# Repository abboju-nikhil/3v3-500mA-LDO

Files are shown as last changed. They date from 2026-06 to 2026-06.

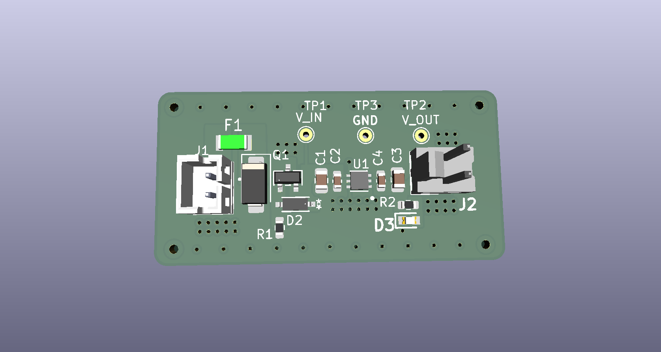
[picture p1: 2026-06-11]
Layout/3D_Image.png

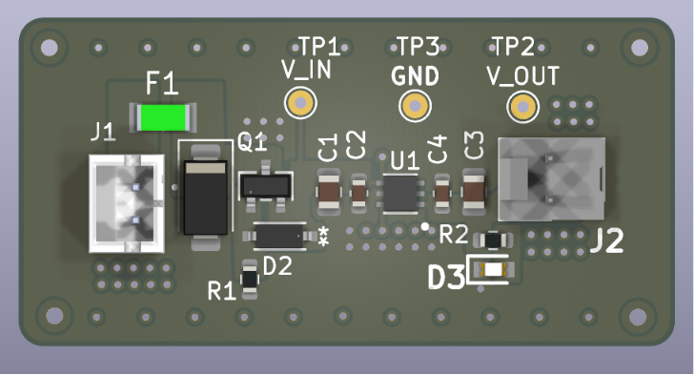
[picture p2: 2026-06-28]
Layout/3D image front.png

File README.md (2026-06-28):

# Single-Cell Li-Ion 3.3V / 500mA Low-Noise Power Supply

> A compact, robust, low-noise **3.3V linear regulator PCB** designed for **single-cell Li-ion batteries**, featuring comprehensive input protection, thermal optimization, and debugging support. Ideal for embedded systems, RF modules, sensors, and precision analog applications. 

---

## 📌 Overview

This project implements a **2-layer PCB** that converts the output of a **single-cell Li-ion battery (3.8V–4.2V)** into a clean, regulated **3.3V** supply capable of delivering up to **500mA** continuous current.

The design emphasizes:

* Low output noise
* High reliability
* Battery efficiency
* Robust input protection
* Thermal performance
* Easy testing and debugging

---

## ✨ Features

* 🔋 Single-cell Li-ion input (3.8V–4.2V)
* ⚡ Fixed 3.3V regulated output
* 🔌 500mA continuous output current
* 🛡 Reverse polarity protection
* ⚠ Resettable overcurrent protection (PTC Fuse)
* ⚡ TVS surge & ESD protection
* 🔥 Thermal pad with via array
* 💡 Power indication LED
* 📈 Dedicated test points
* 🧩 2-layer PCB with optimized power routing

---

## 📊 Specifications

| Parameter | Value |
| --- | --- |
| Input Voltage | 3.8V–4.2V DC |
| Output Voltage | 3.3V DC |
| Output Current | 500mA Max |
| Typical Load | 450mA |
| Operating Temperature | 0°C–70°C |
| PCB Layers | 2 |
| Board Size | <40mm × 20mm |

---

# Architecture

```text
Li-Ion Battery
      │
      ▼
Resettable PTC Fuse
      │
      ▼
TVS Diode Protection
      │
      ▼
P-Channel MOSFET
(Reverse Polarity Protection)
      │
      ▼
LP5912-3.3 LDO
      │
      ▼
Output Capacitors
      │
      ▼
3.3V Output Connector
```

---

# Main Components

| Reference | Part | Purpose |
| --- | --- | --- |
| U1 | LP5912-3.3DRVR | 500mA Low-Noise LDO |
| Q1 | DMP2035U-7 | Reverse Polarity Protection |
| F1 | MF-NSMF110-2 | Resettable PTC Fuse |
| D1 | SMAJ5.0CA | TVS Surge Protection |
| D2 | BZT52C6V8 | MOSFET Gate Protection |
| D3 | Green LED | Power Indicator |
| C1 | 22µF | Input Bulk Capacitor |
| C2 | 100nF | Input Decoupling |
| C3 | 10µF | Output Stability |
| C4 | 100nF | High-Frequency Filtering |

---

# Protection Features

## Reverse Polarity Protection

A **DMP2035U-7 P-Channel MOSFET** replaces the traditional Schottky diode, providing:

* Lower voltage drop
* Higher efficiency
* Better battery utilization
* Automatic reverse battery protection

---

## Overcurrent Protection

The **MF-NSMF110-2 resettable PTC fuse** protects against:

* Output short circuits
* Component failures
* Excessive current draw

The fuse automatically resets once the fault is removed.

---

## Surge & ESD Protection

A **SMAJ5.0CA TVS diode** protects the input from:

* ESD events
* Hot-plug transients
* Voltage spikes
* Input surges

---

## MOSFET Gate Protection

A **6.8V Zener diode (BZT52C6V8)** limits the gate-to-source voltage to protect the MOSFET during transient events.

---

# Capacitor Configuration

## Input Side

| Component | Function |
| --- | --- |
| 22µF | Bulk energy storage |
| 100nF | High-frequency noise filtering |

Placed close to the regulator input to minimize parasitic inductance.

---

## Output Side

| Component | Function |
| --- | --- |
| 10µF | Stability & transient response |
| 100nF | High-frequency filtering |

Located directly beside the regulator output pin.

---

# Test Points

For simplified debugging and validation:

| Test Point | Signal |
| --- | --- |
| TP1 | VIN |
| TP2 | VOUT |
| TP3 | GND |

Compatible with multimeters and oscilloscopes.

---

# Thermal Design

Worst-case power dissipation:

```text
P = (VIN − VOUT) × IOUT

= (4.2 − 3.3) × 0.5

≈ 0.45 W
```

Thermal improvements include:

* Exposed thermal pad
* Thermal via array
* Continuous ground plane
* Ground stitching vias

These features improve heat dissipation and ensure reliable operation within the specified temperature range.

---

# PCB Layout Highlights

* 2-layer PCB
* Continuous bottom ground plane
* Wide VIN/VOUT copper pours
* Short power paths
* Thermal vias beneath LDO
* Ground stitching
* 45° trace routing
* Clearly labeled silkscreen
* Dedicated debugging test points

---

# Applications

This board is suitable for:

* 🤖 Embedded Systems
* 📡 RF Modules
* 📟 IoT Devices
* 🌡 Sensor Nodes
* 🎧 Low-Noise Analog Circuits
* 🔬 Laboratory Prototypes
* 📷 Portable Electronics

---

# Repository Structure

```text
├── Hardware/
│   ├── Schematic/
│   ├── PCB/
│   ├── Gerbers/
│   └── BOM/
│
├── Images/
│   ├── PCB_3D.png
│   ├── Top_View.png
│   └── Bottom_View.png
│
├── Datasheets/
│
├── Docs/
│   └── Design_Notes.pdf
│
└── README.md
```

---

# Future Improvements

* Buck-Boost version for full battery discharge operation
* Battery charging circuit integration
* Fuel gauge implementation
* USB Type-C power input
* Power-path management
* Load switch enable/disable control

---

# License

This project is released under the **MIT License**.

---

## 👨‍💻 Author

**Nikhil Abboju**
Power Electronics Engineer | PCB Design | Embedded Hardware | KiCad

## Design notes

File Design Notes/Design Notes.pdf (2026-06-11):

## Design Notes – Single-Cell Li-Ion 3.3V / 500mA Regulator Board

### 1 Design Overview

This design implements a compact battery-powered 3.3V regulated power supply intended for embedded, RF, sensor, and low-noise analog applications. The board converts the output of a single-cell Li-ion battery (3.8V–4.2V nominal operating range) into a regulated 3.3V supply capable of delivering up to 500mA continuous output current.
The design incorporates reverse-polarity protection, transient suppression, overcurrent protection, power indication, thermal management, and dedicated test points for validation and debugging.

### 1.1 Key Specifications

Parameter | Value
Input Voltage | 3.8V – 4.2V DC (Single-Cell Li-Ion)
Output Voltage | 3.3V DC
Maximum Output Current 500mA
Typical Application Load | 450mA
Operating Temperature | 0°C to 70°C
PCB Layers | 2
Form Factor | < 40mm × 20mm

### 2 IC Selection

### 2.1 LP5912-3.3DRVR (U1)

The LP5912-3.3DRVR low-noise LDO regulator from Texas Instruments was selected as the primary voltage regulation device.
Key advantages include:
- Fixed 3.3V output
- 500mA output current capability
- Very low dropout voltage
- Low output noise performance
- High power-supply rejection ratio (PSRR)
- Integrated thermal shutdown and current limiting
- Compact WSON package with exposed thermal pad
The LP5912 is particularly well suited for battery-powered applications where low noise and low dropout voltage are critical requirements.

### 3 Protection Circuitry

### 3.1 Reverse Polarity Protection (Q1)

Q1 (DMP2035U-7 P-Channel MOSFET) provides reverse-polarity protection at the battery input. Compared to a conventional Schottky diode solution, the MOSFET introduces significantly lower voltage drop, preserving valuable headroom for the LDO regulator and maximizing battery utilization.
Benefits:
- Low forward voltage loss
- High efficiency
- No significant impact on dropout margin
- Automatic protection against reverse battery insertion

### 3.2 Overcurrent Protection (F1)

F1 (MF-NSMF110-2 Resettable PTC Fuse) provides input overcurrent protection.
The device protects the battery and PCB from excessive current during fault conditions such as:
- Output short circuits
- Component failures
- Input protection failures
The resettable nature of the fuse allows normal operation to resume automatically after fault removal.

### 3.3 Input Transient Protection (D1)

D1 (SMAJ5.0CA) is a bidirectional transient voltage suppressor (TVS) diode connected across the battery input.
Functions:
- ESD protection
- Hot-plug transient suppression
- Input surge suppression
- Protection against positive and negative voltage spikes
The device is located adjacent to the input connector to minimize transient propagation into the remainder of the circuit.

### 3.4 MOSFET Gate Protection (D2)

D2 (BZT52C6V8) is a 6.8V zener diode connected between the MOSFET gate and source. Functions:
- Limits gate-to-source voltage
- Protects the MOSFET from gate overstress
- Improves robustness during transient events

### 4 Input and Output Capacitors

### 4.1 Input Capacitors (C1, C2)

### C1 – 22µF Bulk Capacitor

Provides:
- Input energy storage

- Load transient support
- Battery impedance reduction

### C2 – 100nF Ceramic Capacitor

Provides:
- High-frequency decoupling
- Noise suppression
- Improved regulator stability
Both capacitors are placed close to the LP5912 input pin to minimize parasitic inductance.

### 4.2 Output Capacitors (C3, C4)

### C3 – 10µF Ceramic Capacitor

Primary output capacitor used for:
- Regulator stability
- Load transient response
- Output ripple reduction

### C4 – 100nF Ceramic Capacitor

Provides:
- High-frequency output filtering
- Improved dynamic response
The capacitors are positioned directly adjacent to the regulator output and output connector.

### 5 Power Indicator

### 5.1 LED Indicator (D3)

A green LED is connected to the regulated 3.3V output rail through resistor R2. Functions:
- Visual confirmation of regulator operation
- Output power status indication
The LED illuminates whenever the 3.3V rail is present.

### 6 Test Points

Dedicated test points are provided for validation and troubleshooting.

### Test Point Signal

TP1 | VIN
TP2 | VOUT
TP3 | GND

These test points allow direct probing using multimeters and oscilloscopes without disturbing the circuit.

### 7 Thermal Design

The worst-case regulator dissipation occurs at maximum battery voltage and maximum load current.
Approximate worst-case dissipation:

P ≈ (4.2V − 3.3V) × 0.5A ≈ 0.45W

The LP5912 exposed thermal pad is connected directly to the ground plane through a thermal-via array beneath the package.
Thermal management features include:
- Exposed-pad grounding
- Thermal vias beneath U1
- Additional surrounding ground vias
- Continuous bottom-layer ground plane
These measures improve heat transfer into the PCB and maintain safe operating temperatures across the specified ambient temperature range.

### 8 PCB Layout Decisions

The PCB follows a left-to-right power flow architecture:

Battery Input
↓
PTC Fuse
↓
TVS Protection
↓
P-MOS Reverse Protection
↓
LP5912 LDO
↓
Output Capacitors
↓
Output Connector

This arrangement minimizes power-path length and reduces voltage drop.

### 8.1 Layout Features

- 2-layer PCB construction
- Continuous ground plane on bottom layer
- Ground stitching vias around board perimeter
- Short power paths
- Wide copper regions for VIN and VOUT
- Thermal-via array beneath regulator
- Dedicated test points
- 45° routing practices
- Silkscreen labels for connectors and test points
The layout was optimized for manufacturability, thermal performance, and electrical robustness while remaining within the required board size constraints.

### 9 Conclusion

The completed design provides a compact and robust 3.3V power supply solution for single-cell Li-ion battery applications. The design integrates voltage regulation, reverse-polarity protection, transient suppression, overcurrent protection, thermal management, power indication, and debugging access while maintaining compatibility with standard low-cost 2-layer PCB fabrication processes. The design comfortably supports the specified 500mA output requirement and is suitable for powering embedded systems, RF modules, sensors, and low-noise analog circuitry.

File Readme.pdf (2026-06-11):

Single-Cell Li-Ion 3.3V / 500mA Low- Noise Power Supply

Professional GitHub README Documentation

Project Overview

A compact, low-noise, and highly protected 3.3V power supply designed for battery- powered embedded applications. The design converts a single-cell Li-Ion battery output into a regulated 3.3V rail capable of supplying up to 500mA continuous current. Key Specifications
Input Voltage: 3.8V–4.2V DC
Output Voltage: 3.3V DC
Maximum Output Current: 500mA
Typical Load Current: 450mA PCB Layers: 2
Operating Temperature: 0°C–70°C
Board Size: < 40mm × 20mm

Applications

Embedded Systems, IoT Devices, Wireless Sensor Nodes, RF Modules, Portable Electronics, Low-Noise Analog Circuits, Battery-Powered Development Platforms. Hardware Architecture Battery Input → PTC Fuse → TVS Protection → Reverse Polarity MOSFET → LP5912 LDO Regulator → Output Filtering → 3.3V Output

Major Components

LP5912-3.3DRVR Low-Noise LDO Regulator, DMP2035U-7 P-Channel MOSFET, MF- NSMF110-2 Resettable Fuse, SMAJ5.0CA TVS Diode, BZT52C6V8 Zener Diode. Protection Features
Reverse polarity protection, overcurrent protection, surge suppression, ESD protection, and MOSFET gate protection.

Filtering and Stability

22µF and 100nF input capacitors provide bulk storage and decoupling. 10µF and 100nF output capacitors ensure stability and transient performance. Thermal Design
Worst-case regulator dissipation is approximately 0.45W. Thermal management is achieved using an exposed pad, thermal vias, ground stitching vias, and a continuous ground plane. Test Points TP1: VIN, TP2: VOUT, TP3: GND. PCB Layout Features
2-layer PCB, continuous ground plane, thermal via array, wide power traces, short current paths, 45-degree routing, and clear silkscreen labeling. Project Status
Schematic Complete, PCB Layout Complete, ERC Passed, DRC Passed, Manufacturing Files Generated, Ready for Fabrication. Repository Contents
schematic/, Layout/, Gerber files/, Drill files/, BOM/, Datasheets/, Design Notes/, 3D_Models/, symbols/, footprints/, README.md

Tools Used

KiCad 10, Manufacturer Datasheets, Standard 2-Layer PCB Design Practices. Author
Abboju Nikhil – Power Electronics Engineer | PCB Design Engineer

License

Provided for educational, portfolio, and learning purposes.

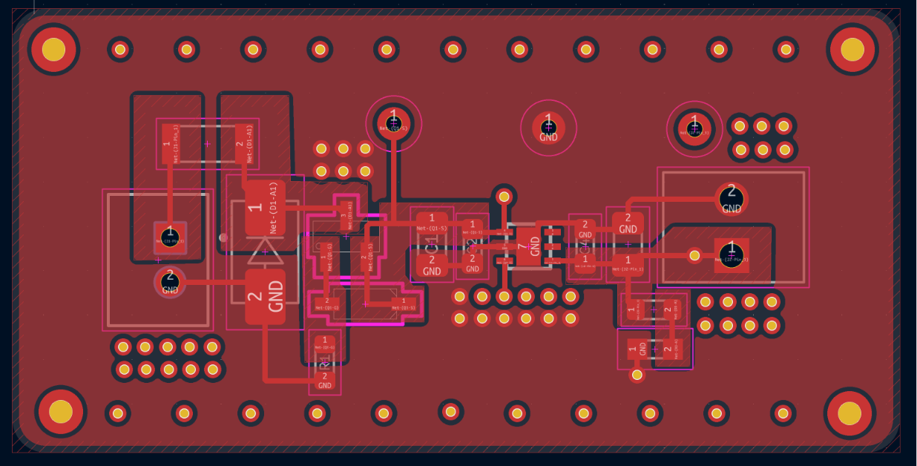
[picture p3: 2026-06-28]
Layout/Fcu.png

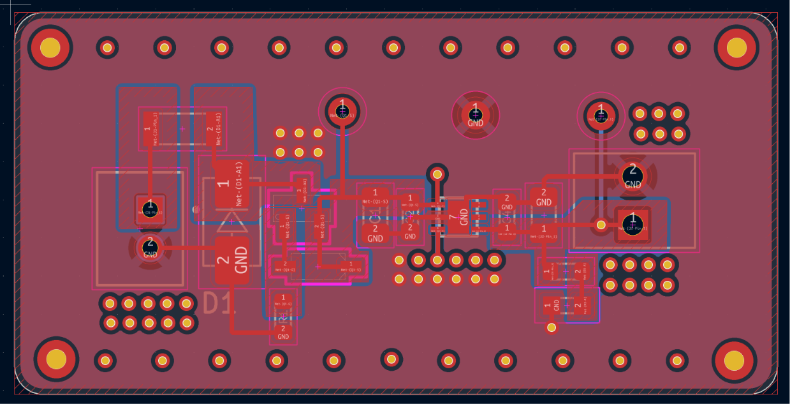
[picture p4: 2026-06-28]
Layout/All Layers .png

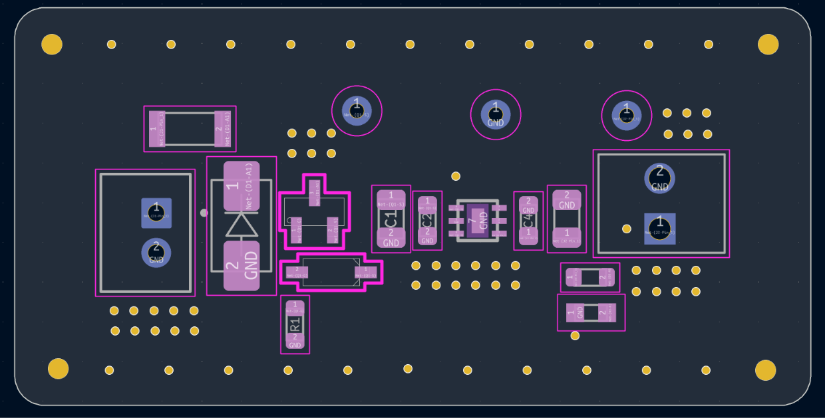
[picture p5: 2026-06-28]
Layout/Edgecuts.png

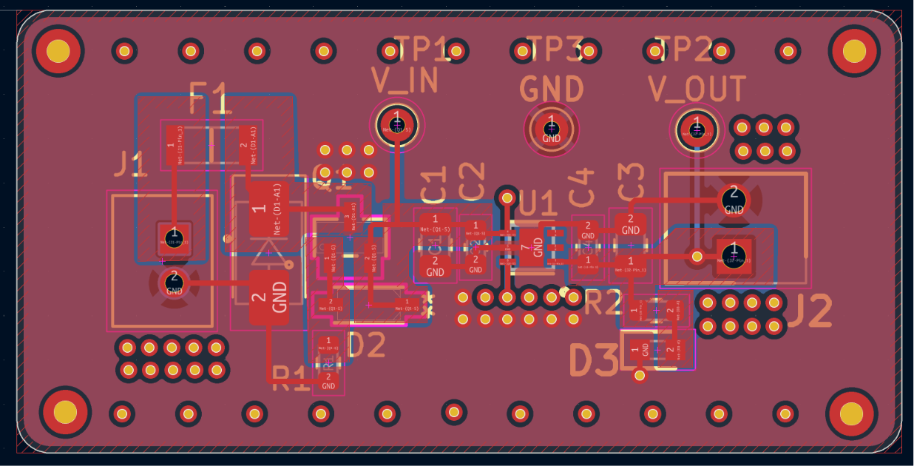
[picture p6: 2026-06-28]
Layout/ALL LAYERS 2.png

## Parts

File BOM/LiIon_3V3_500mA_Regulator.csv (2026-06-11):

Reference | Value | Description | Manufacturer | MPN
C1 | 22uF/16V | 22 uF +/-20% 16V Ceramic Capacitor X5R 0805 (2012 Metric) | Samsung Electro-Mechanics | CL21A226MOQNNNE
C2,C4 | 100nF/16V | CAP CER 0.1UF 16V X7R 0603 | Murata Electronics | GCM188R71C104KA37J
C3 | 10uF/16V | CAP CER 10UF 16V X7R 0805 | Murata Electronics | GRM21BZ71C106KE15L
D1 | SMAJ5.0CA | 400W bidirectional Transient Voltage Suppressor, 5.0Vr, SMA(DO-214AC) | LITTELFUSE | SMAJ5.0CA
D2 | 6.8V | Zener Diode 6.8V, 500mW, SOD-123 | Diodes Incorporated | BZT52C6V8-7-F
D3 | LTST-C190KGKT | Green Indicator LED, 0603 | Lite-On | LTST-C190KGKT
F1 | MF-NSMF110-2 | Fuse, PTC, Resettable, SMD, 1206, 1.1A Bourns 1.1A Surface Mount Resettable Fuse, 6 V | Bourns | MF-NSMF110-2
J1 | JST-PH 2PIN | 2-Pin PH Connector Header, 2.0mm Pitch | JST Sales America Inc. | B2B-PH-K-S
J2 | 2 PIN HEADER | 2-Pin Header, 2.54mm Pitch, THT | Molex | 22-23-2021
Q1 | DMP2035U-7 | P-CH MOSFET, -20V, -3.6A, SOT-23 | Diodes Incorporated | DMP2035U-7
R1 | 100K | RES 100K OHM 1% 1/10W 0603 | YAGEO | RC0603FR-07100KL
R2 | 10K | RES 10K OHM 1% 1/10W 0603 | YAGEO | RC0603FR-0710KL
TP1,TP2,TP3 | GND,V_IN,V_OUT | test point
U1 | LP5912-3.3DRVR | Low-Noise 3.3V LDO, 500mA, WSON-6 | Texas Instruments | LP5912-3.3DRVR

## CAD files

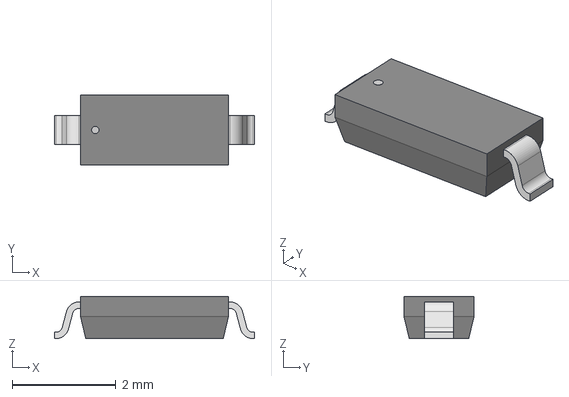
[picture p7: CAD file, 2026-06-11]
3D_Models/SOD123_DIO.step
3.85 x 1.35 x 0.815 mm

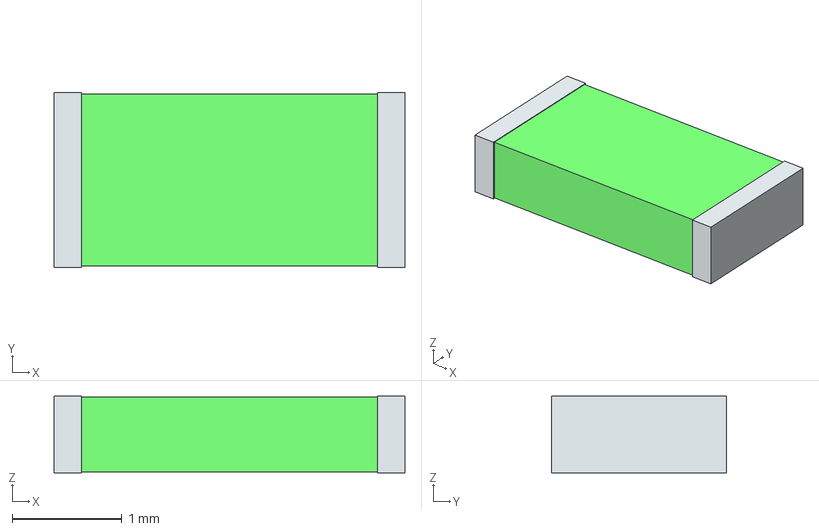
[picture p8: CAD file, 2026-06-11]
3D_Models/MF-NSMF110-2.stp
3.20 x 1.60 x 0.7 mm
term1
term2

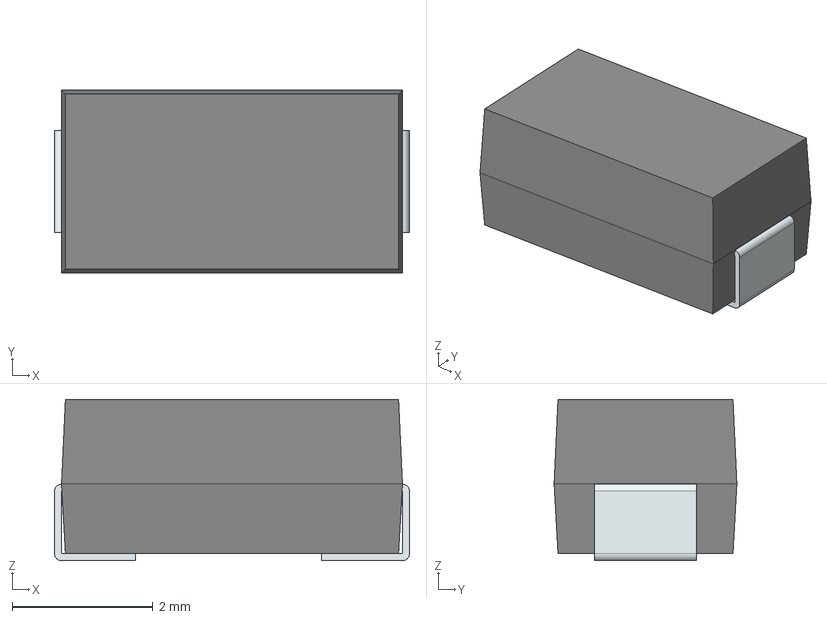
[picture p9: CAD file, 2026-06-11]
3D_Models/SMAJ5.0CA.stp
5.04 x 2.60 x 2.29 mm
FilletPin1
FilletPin2

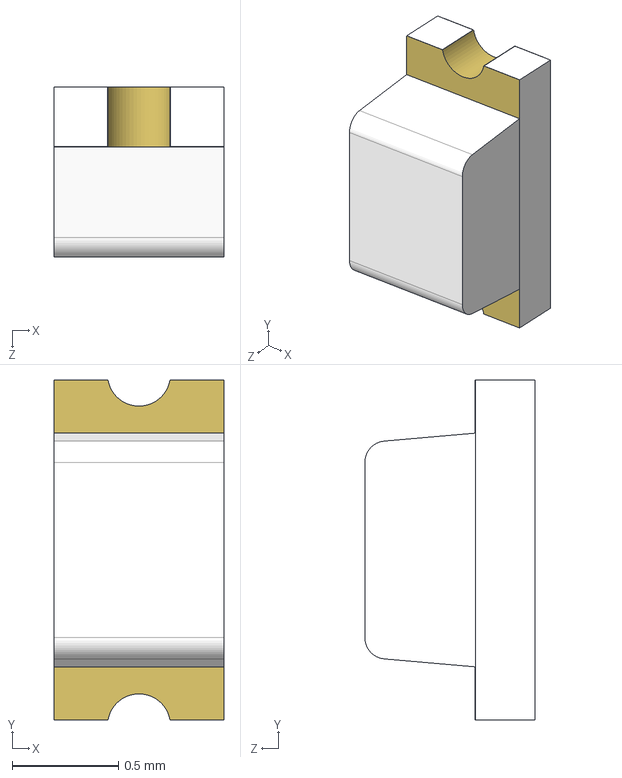
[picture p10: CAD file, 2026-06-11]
3D_Models/LTST-C190KGKT.stp
0.8 x 1.60 x 0.801 mm

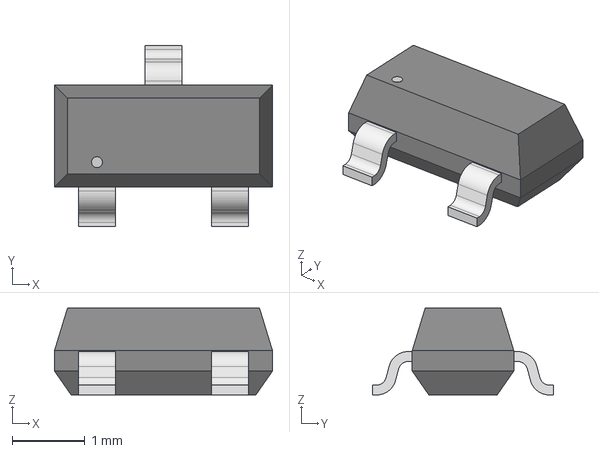
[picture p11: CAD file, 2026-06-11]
3D_Models/DMP2035U-7.step
3.00 x 2.49 x 1.20 mm

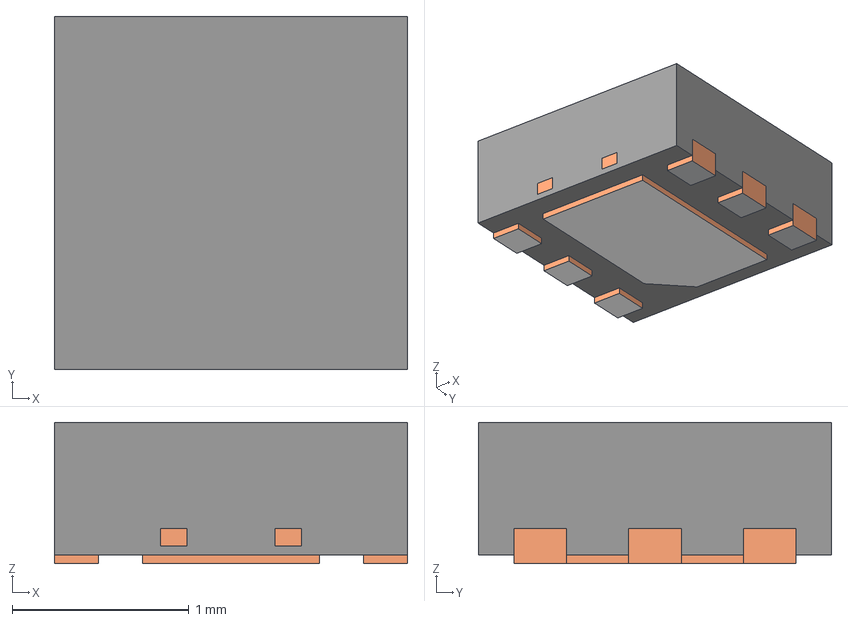
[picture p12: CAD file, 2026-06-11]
3D_Models/LP5912-3.3DRV.stp
2.00 x 2.00 x 0.8 mm
BODY-SON
FRAME-DRV0006A
PIN1-ID

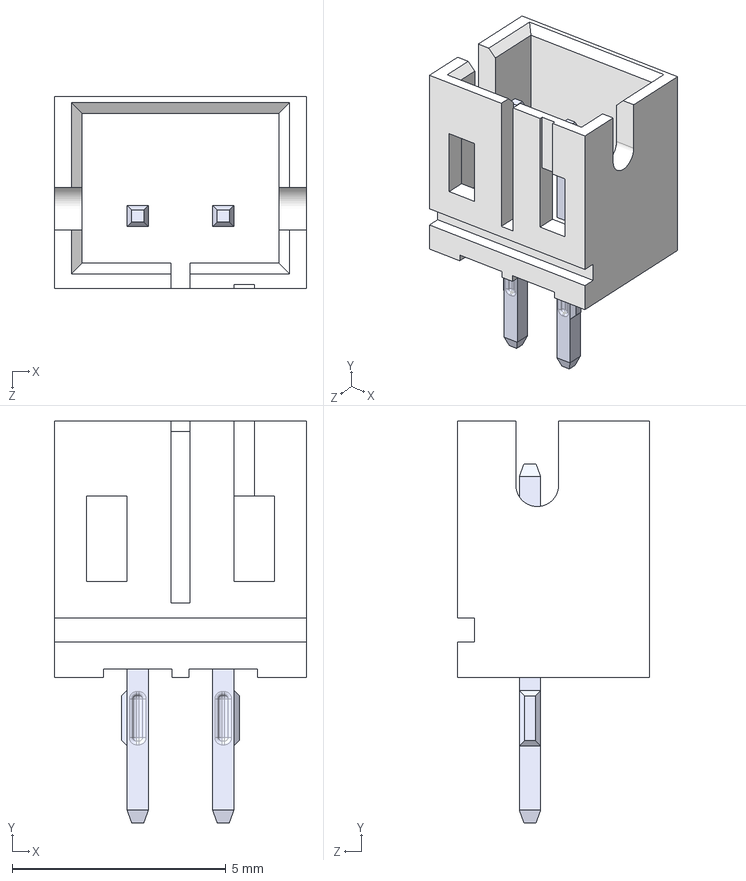
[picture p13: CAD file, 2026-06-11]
3D_Models/B2B-PH-K-S.STEP
5.90 x 9.40 x 4.50 mm

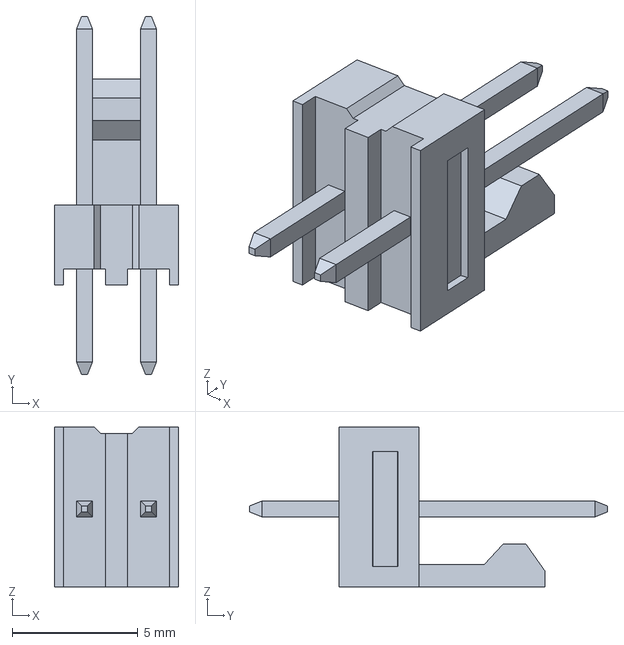
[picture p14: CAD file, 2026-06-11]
3D_Models/0022232021.stp
4.93 x 14.2 x 6.35 mm

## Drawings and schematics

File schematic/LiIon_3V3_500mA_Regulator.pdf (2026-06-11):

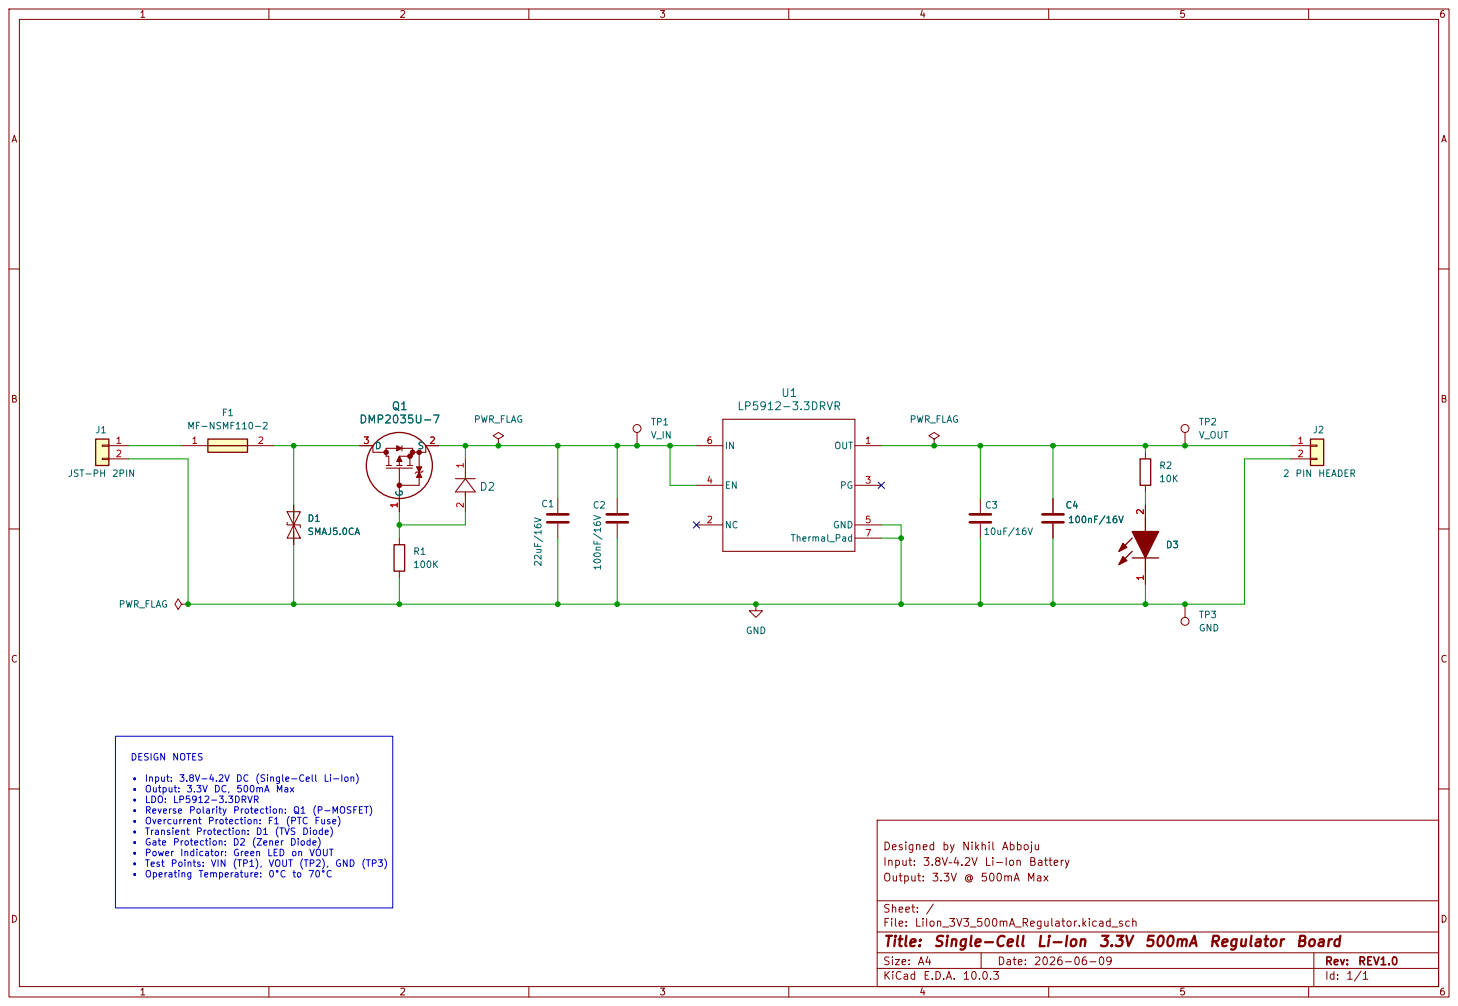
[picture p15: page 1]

DESIGN NOTES • Input: 3.8V-4.2V DC (Single-Cell Li-Ion) • Output: 3.3V DC, 500mA Max • LDO: LP5912-3.3DRVR • Reverse Polarity Protection: Q1 (P-MOSFET) • Overcurrent Protection: F1 (PTC Fuse) • Transient Protection: D1 (TVS Diode) • Gate Protection: D2 (Zener Diode) • Power Indicator: Green LED on VOUT • Test Points: VIN (TP1), VOUT (TP2), GND (TP3) • Operating Temperature: 0°C to 70°C

Designed by Nikhil Abboju
Input: 3.8V–4.2V Li-Ion Battery
Output: 3.3V @ 500mA Max

Sheet: /
File: LiIon_3V3_500mA_Regulator.kicad_sch
Title: Single-Cell Li-Ion 3.3V 500mA Regulator Board

Size: A4 | Rev: REV1.0
KiCad E.D.A. 10.0.3 | Id: 1/1

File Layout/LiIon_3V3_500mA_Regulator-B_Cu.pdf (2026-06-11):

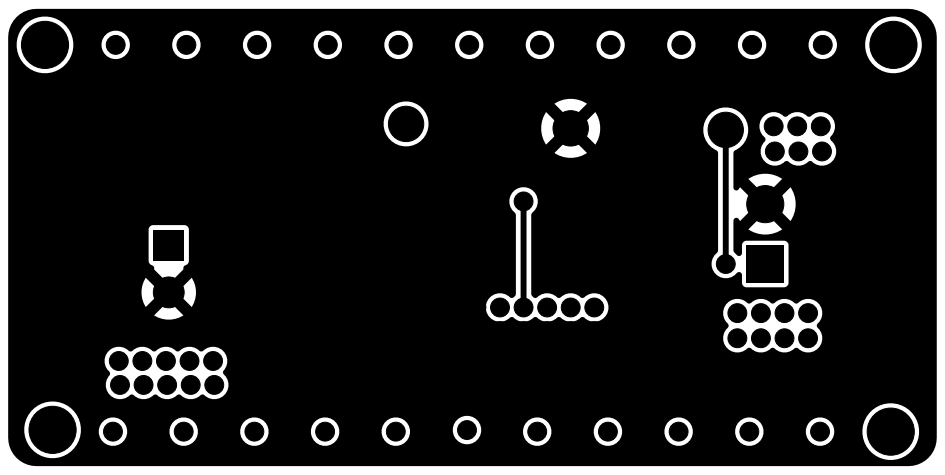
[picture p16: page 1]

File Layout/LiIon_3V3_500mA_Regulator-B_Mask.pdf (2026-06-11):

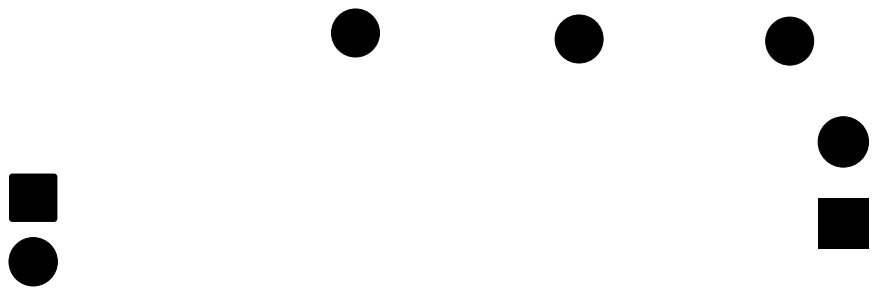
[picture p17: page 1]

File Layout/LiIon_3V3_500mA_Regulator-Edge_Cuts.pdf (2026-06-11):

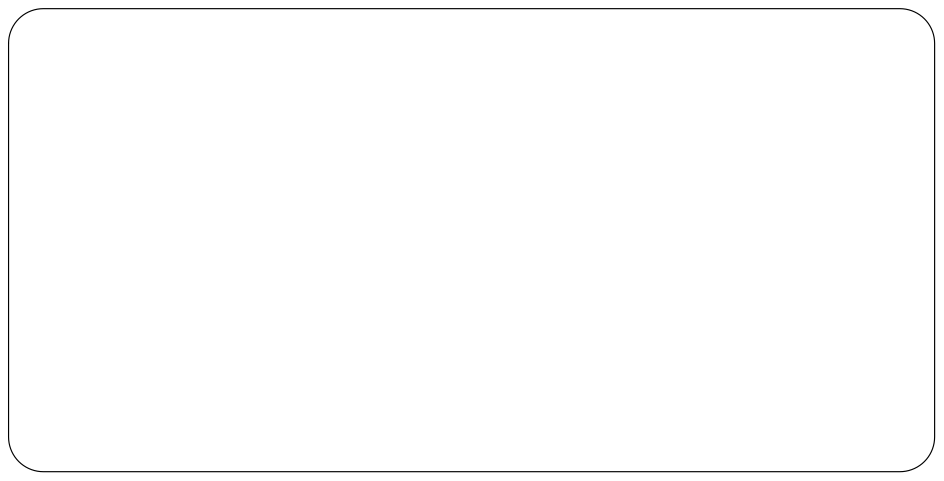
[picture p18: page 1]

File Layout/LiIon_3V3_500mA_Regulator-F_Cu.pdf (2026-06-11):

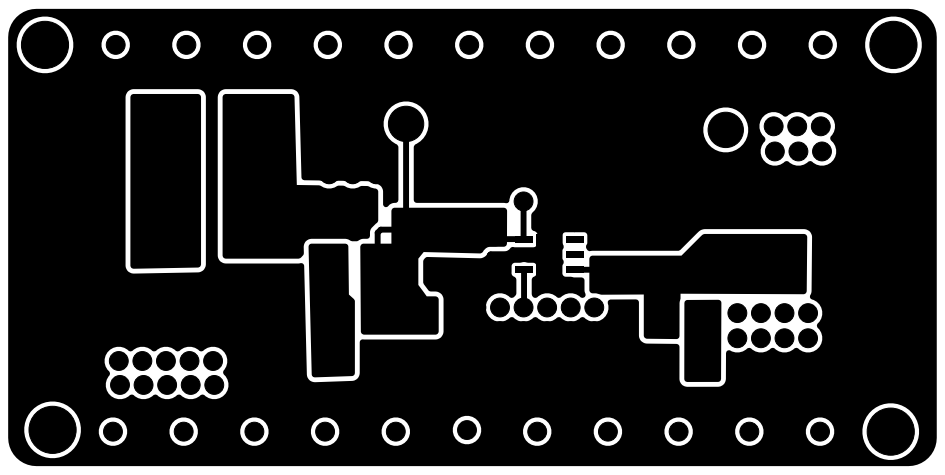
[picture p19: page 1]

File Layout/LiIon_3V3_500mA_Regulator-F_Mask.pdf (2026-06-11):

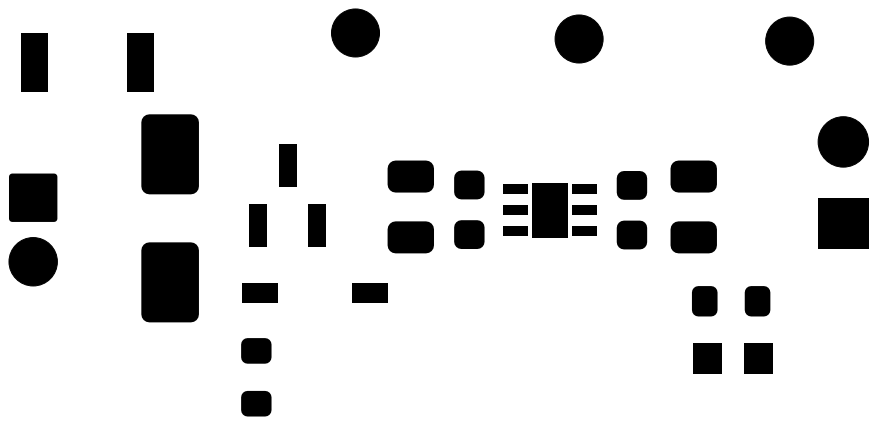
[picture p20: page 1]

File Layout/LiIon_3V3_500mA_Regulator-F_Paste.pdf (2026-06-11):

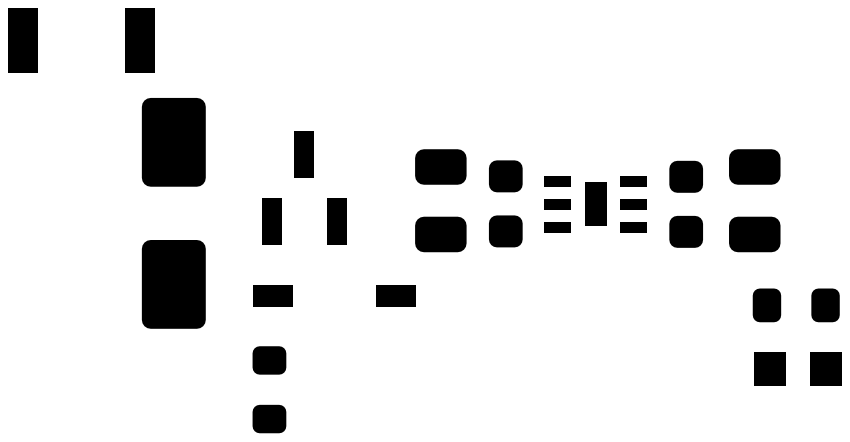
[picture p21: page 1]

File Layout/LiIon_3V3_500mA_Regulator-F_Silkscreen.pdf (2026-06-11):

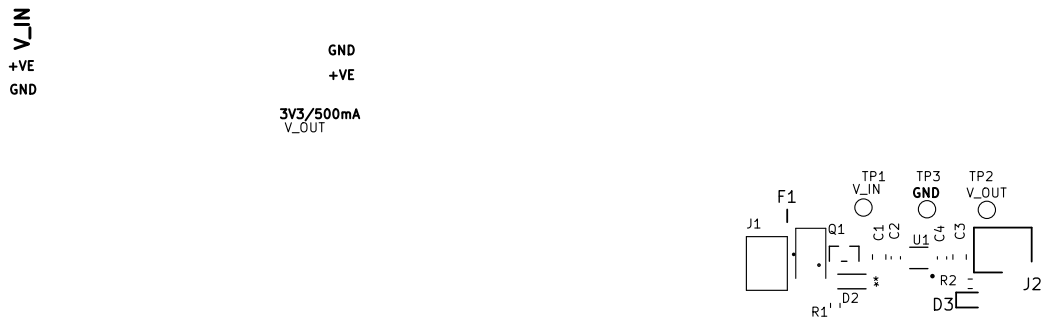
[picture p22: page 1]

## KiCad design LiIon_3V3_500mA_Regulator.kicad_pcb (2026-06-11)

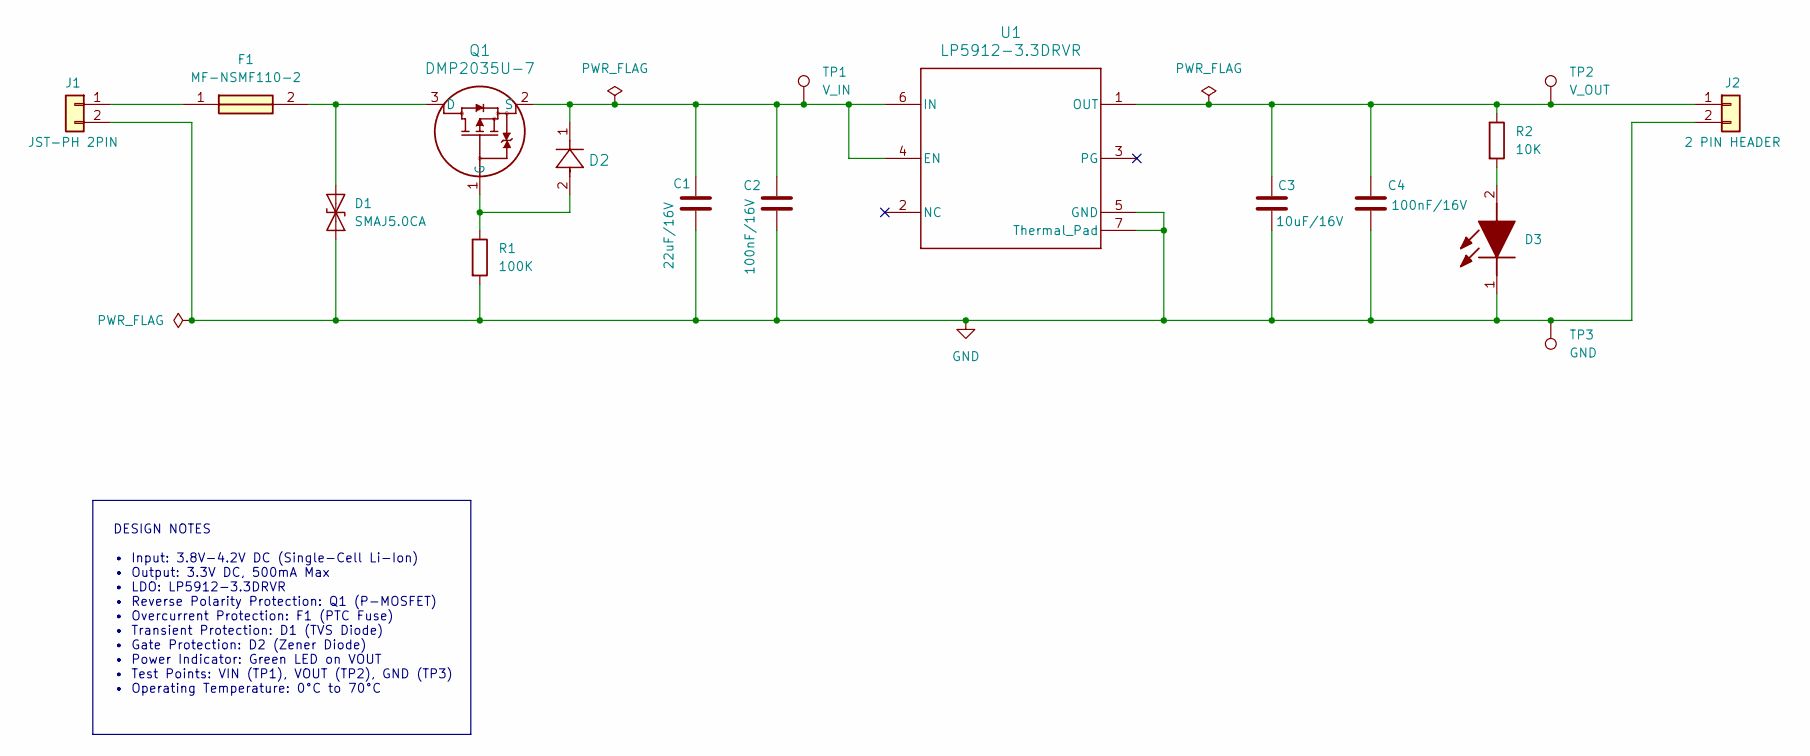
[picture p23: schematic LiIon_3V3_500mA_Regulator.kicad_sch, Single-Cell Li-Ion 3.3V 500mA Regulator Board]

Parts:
C1: 22uF/16V; C_0805_2012Metric; MPN CL21A226MOQNNNE
C2, C4: 100nF/16V; C_0603_1608Metric; MPN GCM188R71C104KA37J
C3: 10uF/16V; C_0805_2012Metric; MPN GRM21BZ71C106KE15L
D1: SMAJ5.0CA; D_SMA; MPN SMAJ5.0CA
D2: 6.8V; SOD123_DIO; MPN BZT52C6V8-7-F
D3: LTST-C190KGKT; LEDC1608X80N; MPN LTST-C190KGKT
F1: MF-NSMF110-2; FUSC3216X70N; MPN MF-NSMF110-2
J1: JST-PH 2PIN; B2B-PH-K-S; MPN B2B-PH-K-S
J2: 2 PIN HEADER; 22-23-2021; MPN 22-23-2021
Q1: DMP2035U-7; MPN DMP2035U-7
R1: 100K; R_0603_1608Metric; MPN RC0603FR-07100KL
R2: 10K; R_0603_1608Metric; MPN RC0603FR-0710KL
TP1: V_IN; TestPoint_THTPad_D1.5mm_Drill0.7mm
TP2: V_OUT; TestPoint_THTPad_D1.5mm_Drill0.7mm
TP3: GND; TestPoint_THTPad_D1.5mm_Drill0.7mm
U1: LP5912-3.3DRVR; U1; MPN LP5912-3.3DRVR

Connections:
GND: C1.2, C2.2, C3.2, C4.2, D1.2 (A2), D3.1 (K), J1.2, J2.2, R1.2, TP3.1 (1_1), U1.5 (GND), U1.7 (Thermal_Pad)
unnamed: D1.1 (A1), F1.2, Q1.3 (D)
unnamed: D3.2 (A), R2.2
unnamed: F1.1, J1.1
unnamed: C3.1, C4.1, J2.1, R2.1, TP2.1 (1_1), U1.1 (OUT)
unnamed: D2.2, Q1.1 (G), R1.1
unnamed: C1.1, C2.1, D2.1, Q1.2 (S), TP1.1 (1_1), U1.4 (EN), U1.6 (IN)

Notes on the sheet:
DESIGN NOTES • Input: 3.8V-4.2V DC (Single-Cell Li-Ion) • Output: 3.3V DC, 500mA Max • LDO: LP5912-3.3DRVR • Reverse Polarity Protection: Q1 (P-MOSFET) • Overcurrent Protection: F1 (PTC Fuse) • Transient Protection: D1 (TVS Diode) • Gate Protection: D2 (Zener Diode) • Power Indicator: Green LED on 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

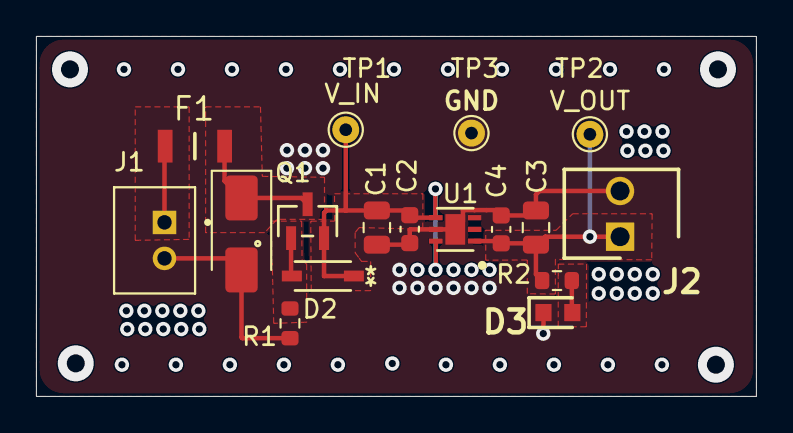
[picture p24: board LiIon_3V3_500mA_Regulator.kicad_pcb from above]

Board: 2 copper layers, 40.0 x 20.0 mm, 17 parts (0 on the bottom side), 7 nets.
